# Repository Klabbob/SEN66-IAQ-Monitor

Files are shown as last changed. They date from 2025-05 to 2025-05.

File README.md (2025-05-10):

# IAQ Monitor

An Indoor Air Quality Monitor using the [Sensirion SEN66](https://sensirion.com/de/produkte/katalog/SEN66) sensor and a [LilyGo T-Display-S3](https://lilygo.cc/products/t-display-s3?variant=42284559827125)

<p align="center">
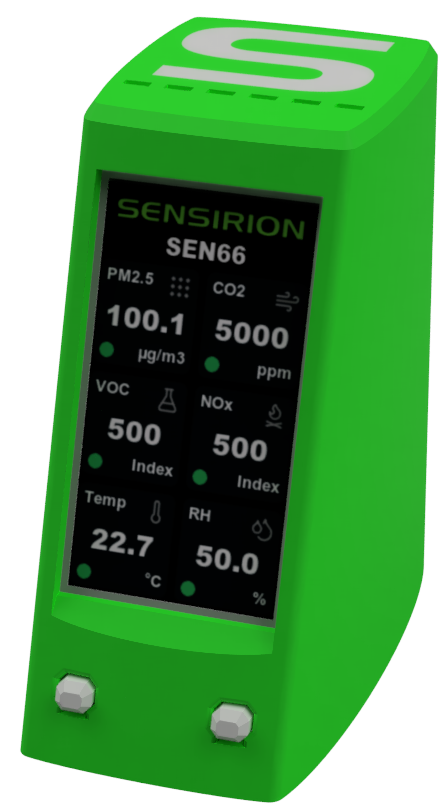
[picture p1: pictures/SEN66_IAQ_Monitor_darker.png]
SEN66 IAQ Monitor
  
</p>

## Features

- Real-time monitoring of:
  - Particle mass concentrations (PM1.0, PM2.5, PM4.0, PM10.0)
  - Temperature
  - Humidity
  - VOC
  - NOx
  - CO2
- Chart screens with 2min30, 60min and 24h resolution
- Settings menu:
  - Perform forced recalibration of CO2
  - Set alititude for CO2 compensation (apply this before the forced recalibration)
  - Switch resolution on chart screen
  - Change screen Brightness
- Serial output with both processed and raw values

## Hardware Requirements

- [Sensirion SEN66](https://sensirion.com/de/produkte/katalog/SEN66), which can be had at many distributors
- [LilyGo T-Display-S3](https://lilygo.cc/products/t-display-s3?variant=42284559827125) (make sure to get the non-touch version without soldered pin headers)
- [SEN5x Jumper Wire](https://sensirion.com/de/produkte/katalog/SEN5x-jumper-wire) - alternatively you can use [Sparkfun JST-GHR-06V Cable](https://www.sparkfun.com/breadboard-to-jst-ghr-06v-cable-6-pin-x-1-25mm-pitch.html), just be ware that the colors are different! Both cables can be had at many distributors.
- [USB C Breackout Board](https://www.sparkfun.com/sparkfun-usb-c-breakout.html) (Knock-offs can also be found on Aliexpress and the likes)
- 3D Printer to print the housing
- M3x10 Bolt
- (optional) [M3 threaded insert](https://www.3djake.com/3djake/threaded-inserts-50-piece-set)

## Software Requirements

- VSCode with PlatformIO (or forks of VSCode like [Cursor](https://www.cursor.com/))

## Hardware Assembly

### 3D Printing

In the [3D Models](3D%20Models) folder, you can find the Fusion 360 source file and STEP-File exports of all the parts that you need. You need the following parts:
- Top Shell - Different versions for:
  - With Logo for dual color printing or without 
  - With heat insert or without if you want to screw directly into the plastic
- Bottom Shell- Two versions for:
  - Original Sparkfun USB C boards with 1.6mm PCB thickness
  - Version for some Aliexpress knockoffs that can be only 1.2mm thick
- Buttons

Print the parts in the following orientation. The only part that needs some paint-on support is the area of the bottom shell where you can find the USB port of the LilyGo T-Display S3

<p align="center">
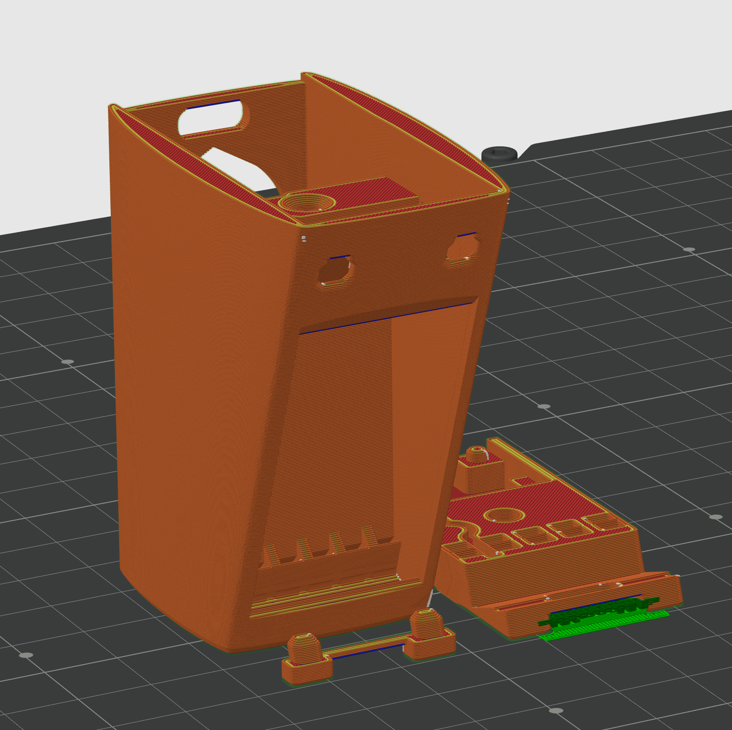
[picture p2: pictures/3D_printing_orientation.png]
3D Print Preview
  
</p>

After printing make sure that the inside part of the top shell where the buttons should sit is flat.

### Wiring

<p align="center">
  Wiring Diagram
</p>

The instruction is for the [SEN5x Jumper Wire](https://sensirion.com/de/produkte/katalog/SEN5x-jumper-wire), if you use the [Sparkfun JST-GHR-06V Cable](https://www.sparkfun.com/breadboard-to-jst-ghr-06v-cable-6-pin-x-1-25mm-pitch.html), just be ware that the colors are different!

- Remove the purple and blue cable from the connector
- cut the remaining 4 cables to a length of 110mm
- from the leftovers cut 75mm of the black and red wire
- Connect the USB C Board
  - 75mm:
    - Red to VBUS
    - Black to GND
- Connect T-Display S3
  - 75mm:
    - Red to 5V
    - Black to GND
  - 110mm with connector:
    - Red to 3V3
    - Black to GND
    - Green to GPIO18
    - Yellow to GPIO17

### Assembly

0. If you chose the version with insert, use the soldering iron to insert the M3 threaded insert in to the top shell
1. Insert the LilyGo T-Display-S3 into the top shell
2. Insert the buttons
3. Connect the SEN66 and push it in
4. Clip in the wires from the SEN66 and push the remaining wires in to the cavity behind the T-Display-S3
5. Insert the USB C breakout board into the bottom shell and push the wires in the canal
6. Close everything up with the screw, make sure not to pinch any wires. Test the buttons for smooth operation. If the they are not clicky, you either have to smooth the surface on the inside where the button sit, or you can try to have the screw a bit looser.

## Installation

1. Clone the repository:
   ```bash
   git clone https://github.com/Klabbob/IAQ-Monitor.git
   ```

2. Open the project in PlatformIO

3. Install dependencies:
   ```bash
   pio lib install
   ```

4. Build and upload to your device

## Sensor Data

<details>
<summary>Sensor Data</summary>

### Processed Values

- Particle Mass Concentrations (μg/m³):
  - PM1.0
  - PM2.5
  - PM4.0
  - PM10.0

- Environmental Parameters:
  - Temperature (°C)
  - Humidity (%RH)

- Air Quality Indices (0-500):
  - VOC Index
  - NOx Index

- Gas Concentration:
  - CO2 (ppm)

### Raw Values

- Environmental Parameters:
  - Raw Humidity: Scaled with factor 100 (RH [%] = value / 100)
  - Raw Temperature: Scaled with factor 200 (T [°C] = value / 200)

- Gas Sensors:
  - Raw VOC: Raw ticks without scale factor
  - Raw NOx: Raw ticks without scale factor
  - Raw CO2: Not interpolated CO₂ concentration [ppm]

### Raw Value Notes

- If humidity or temperature values are unknown, 0x7FFF is returned
- If VOC, NOx, or CO2 values are unknown, 0xFFFF is returned
- During the first 10-11 seconds after power-on or device reset, NOx will be 0xFFFF
- During the first 5-6 seconds after power-on or device reset, CO2 will be 0xFFFF
</details>

## Serial Output

The device outputs data in the following tab-separated format:

```
PM1.0	PM2.5	PM4.0	PM10.0	RH	T	VOC	NOx	CO2	Raw RH	Raw T	Raw VOC	Raw NOx	Raw CO2
12.3	34.5	56.7	78.9	45.6	23.4	120	80	400	45.60	23.40	100	80	400
```

- The first line is a header describing each column.
- The second and subsequent lines are sensor readings, tab-separated, in the order shown above.

## Development

### UI
The UI is built with [SquareLine Studio](https://squareline.io/downloads). Due to the limitiations of the free license tier, the setting screens are designed in a separate project. The projects can be found in the [src/ui_Settings](src/ui_Settings) folder. 

You can make changes to the UI by opening the project file (.spj) in SquareLine Studio. Go to File->Project Settings and set the UI Files Export Path to the `src/ui` or `src/ui_Settings` respecitively as SquareLine Studio only takes absolut paths. Then make your adjustments and go to Export->Export UI Files.

It is necessary to manually assembly the two ui exports. The main screens will be directly exported to the [src/ui](src/ui) folder, the setting screens to the [src/ui_Settings](src/ui_Settings) folder. 

1. Copy over all screen files (ui_XYZScreen.c) to [src/ui](src/ui) from [src/ui_Settings](src/ui_Settings)
2. Copy over all image files (ui_img_XYZ.c) that are not already in [src/ui](src/ui)
3. Copy all unique parts of ui.c and ui.h in [src/ui_Settings](src/ui_Settings) into the respective files in [src/ui](src/ui)
4. Repeat the same for the filelist.txt and CMakeLists.text files.

Contgratulations, you merged both projects. If you add new screens, make sure to update display_task.h and display_task.cpp. If you add a lot of new stuff, you might need to increase LV_MEM_SIZE in lv_conf.h

### Known Bugs

- Screen sometimes not fully refreshing when switching screen showing remenants of previous screens
- ledcWrite function in setDisplayBrightness not always setting 100% duty cycle correctly

### TODO

- [ ] Implement offset compensation based on screen brightness

## License

This project is licensed under the MIT License - see the LICENSE file for details.

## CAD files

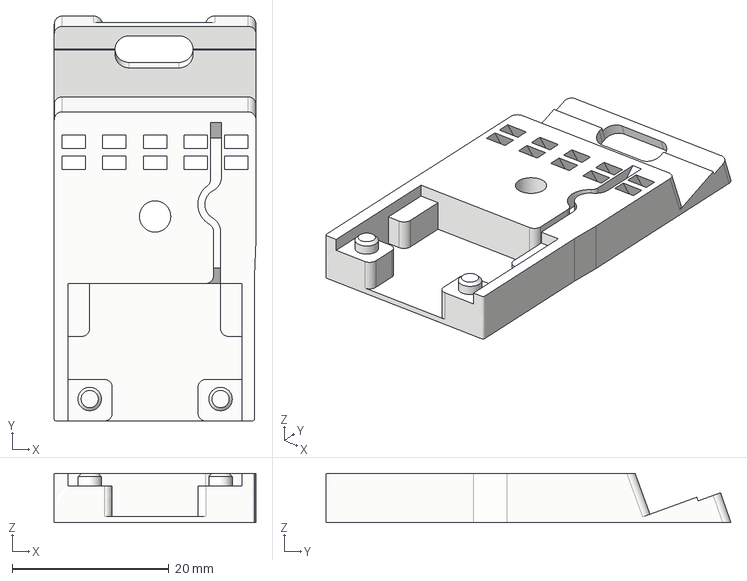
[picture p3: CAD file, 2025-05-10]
3D Models/SEN6x IAQ Bottom Shell 1_6mm.step
25.8 x 51.7 x 6.26 mm

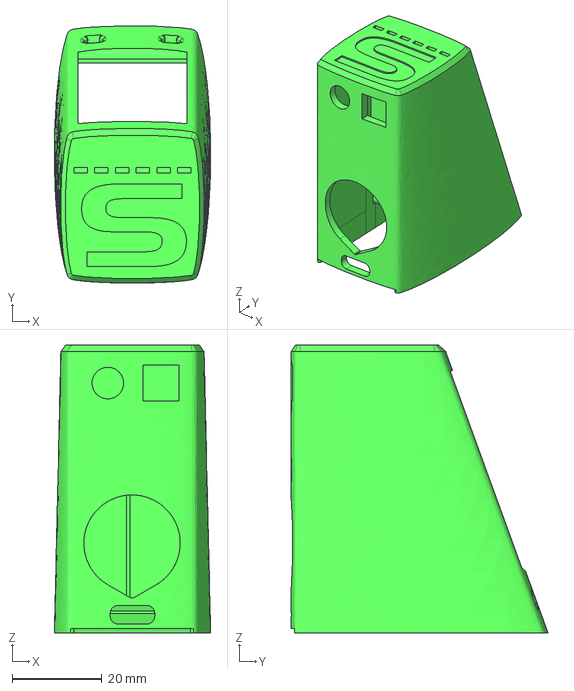
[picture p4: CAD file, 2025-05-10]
3D Models/SEN6x IAQ Top Shell without insert with Logo.step
34.9 x 57.4 x 64.3 mm
Top Shell
Top Shell no insert

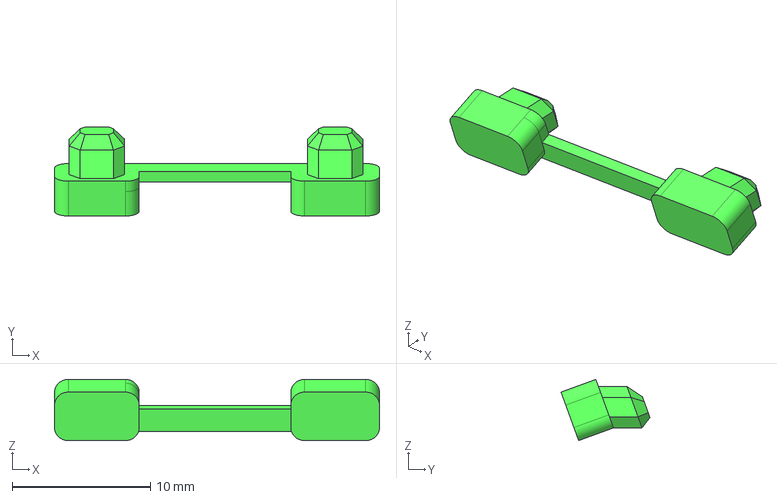
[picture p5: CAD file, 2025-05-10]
3D Models/SEN6x IAQ Buttons.step
23.5 x 6.43 x 4.42 mm

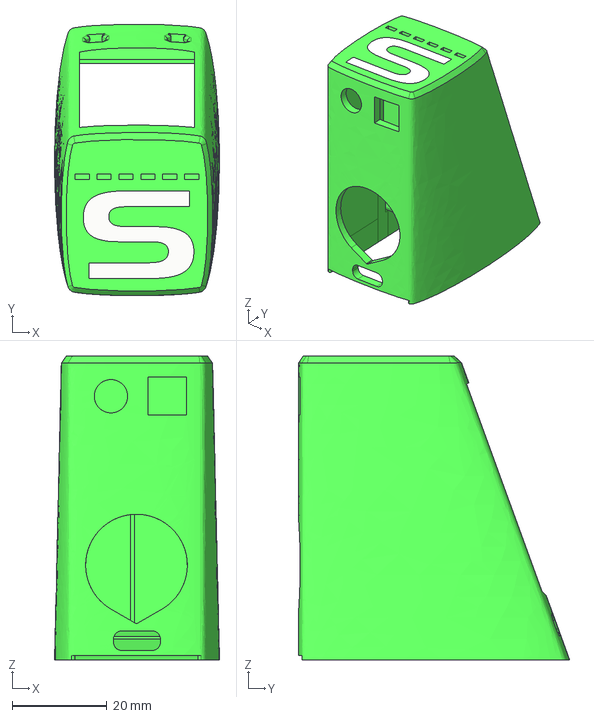
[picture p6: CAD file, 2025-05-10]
3D Models/SEN6x IAQ Top Shell without Logo.step
34.9 x 57.4 x 64.3 mm

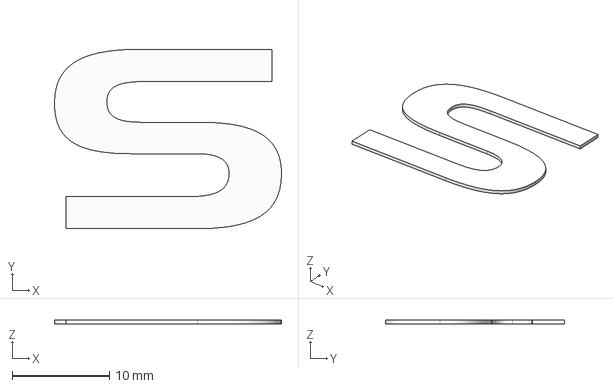
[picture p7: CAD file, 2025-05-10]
3D Models/SEN6x IAQ Logo.step
23.4 x 18.5 x 0.4 mm

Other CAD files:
3D Models/SEN6x IAQ Bottom Shell 1_2mm.step
3D Models/SEN6x IAQ Top Shell with Logo.step
3D Models/SEN6x IAQ Top Shell without insert without Logo.step

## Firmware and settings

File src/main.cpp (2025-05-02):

#include "Arduino.h"
#include <WiFi.h>
#include "esp_bt.h"
#include "esp_bt_main.h"
#include "task_hierarchy.h"
#include "tasks/task_utils.h"
#include "tasks/serial_logging_task.h"
#include "tasks/i2c_scan_task.h"
#include "tasks/live_data_manager.h"
#include "tasks/display_task.h"
#include "tasks/button_handler.h"
#include "definitions.h"

// Global variables
TaskHandle_t xSerialLogTaskHandle = nullptr;
TaskHandle_t xI2CScanTaskHandle = nullptr;

void disableWireless() {
    // Disable WiFi
    WiFi.disconnect(true);  // Disconnect and delete credentials
    WiFi.mode(WIFI_OFF);    // Set WiFi to off mode
    
    // Disable Bluetooth
    btStop();              // Stop Bluetooth
    esp_bt_controller_disable();  // Disable BT controller
    esp_bt_controller_mem_release(ESP_BT_MODE_BTDM);  // Release BT memory
}

void setup() {
    Serial.begin(115200);
    
    #ifdef DEBUG_MODE
    // Wait for serial to be ready
    while (!Serial) delay(100);
    Serial.println("SEN66 Sensor Test Starting...");
    #endif

      // Set CPU frequency to 80MHz
    setCpuFrequencyMhz(80);
    
    // Disable wireless features
    disableWireless();

    // Enable power from 5v Pin or Battery 
    pinMode(PIN_POWER_ON, OUTPUT);
    digitalWrite(PIN_POWER_ON, 1);
    
    // Launch LiveDataManager task first
    if (launchTaskWithVerification(
        LiveDataManager::liveDataManagerTask,
        LIVE_DATA_TASK_NAME,
        LIVE_DATA_STACK_SIZE,
        nullptr,
        TIER_I_PRIORITY,
        &LiveDataManager::xLiveDataManagerTaskHandle
    ) != pdPASS) {
        Serial.println("Failed to create LiveDataManager task");
        while (1) delay(100);
    }
    
    // Launch I2C scan task
    if (launchTaskWithVerification(
        I2CScanTask::i2cScanTask,
        I2C_SCAN_TASK_NAME,
        I2C_STACK_SIZE,
        nullptr,
        TIER_II_PRIORITY,
        &xI2CScanTaskHandle
    ) != pdPASS) {
        Serial.println("Failed to create I2C scan task");
        while (1) delay(100);
    }
    
    #ifdef SERIAL_LOGGING
    // Launch serial logging task
    if (launchTaskWithVerification(
        serialLoggingTask,
        SERIAL_LOG_TASK_NAME,
        DEFAULT_STACK_SIZE,
        nullptr,
        TIER_III_PRIORITY,
        &xSerialLogTaskHandle
    ) != pdPASS) {
        Serial.println("Failed to create serial logging task");
        while (1) delay(100);
    }
    #endif
    // Launch display task
    if (launchTaskWithVerification(
        DisplayTask::displayTask,
        DISPLAY_TASK_NAME,
        DISPLAY_STACK_SIZE,
        nullptr,
        TIER_I_PRIORITY,
        &DisplayTask::xDisplayTaskHandle
    ) != pdPASS) {
        Serial.println("Failed to create display task");
        while (1) delay(100);
    }

    // Launch button task
    if (launchTaskWithVerification(
        ButtonHandler::buttonTask,
        "ButtonTask",
        DEFAULT_STACK_SIZE,
        nullptr,
        TIER_II_PRIORITY,
        &ButtonHandler::xButtonTaskHandle
    ) != pdPASS) {
        Serial.println("Failed to create button task");
        while (1) delay(100);
    }
    
    Serial.println("Tasks initialized successfully!");
    Serial.println("Starting measurements...");
    Serial.println("----------------------------------------");
}

void loop() {
    // Do nothing, all operations being taken care of by tasks
    vTaskSuspend(NULL);  // Suspend the main loop task
} 

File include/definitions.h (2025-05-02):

#pragma once

#include <cstdint>

// uncomment to enable debug mode
// #define DEBUG_MODE

// uncomment to enable serial logging
#define SERIAL_LOGGING

// I2C Configuration
#define SENSOR_I2C_ADDRESS 0x6B
#define SENSOR_READY_CHECK_INTERVAL 1000    // ms
#define SENSOR_READY_RECHECK_TIME 100       // ms


//STAR Engine Parameters:
//  Acceleration
#define K                            20
#define P                            20
#define T1                           100
#define T2                           300

// Slot 0
#define SLOT_0_OFFSET                -620   //-3.1°C scaled by 200
#define SLOT_0_SLOPE                 0      //no slope
#define SLOT_0_TIME_CONSTANT         700    //Tau63 of 700 seconds
#define SLOT_0_SLOT_TIME             0      //Slot 0

// Preferences namespace and key
#define PREF_NAMESPACE              "sensor_config"
#define PREF_ALTITUDE_KEY           "altitude"

/*ESP32S3*/
#define PIN_LCD_BL                   38

#define PIN_LCD_D0                   39
#define PIN_LCD_D1                   40
#define PIN_LCD_D2                   41
#define PIN_LCD_D3                   42
#define PIN_LCD_D4                   45
#define PIN_LCD_D5                   46
#define PIN_LCD_D6                   47
#define PIN_LCD_D7                   48

#define PIN_POWER_ON                 15

#define PIN_LCD_RES                  5
#define PIN_LCD_CS                   6
#define PIN_LCD_DC                   7
#define PIN_LCD_WR                   8
#define PIN_LCD_RD                   9

#define PIN_BUTTON_LEFT              0
#define PIN_BUTTON_RIGHT             14
#define PIN_BAT_VOLT                 4

#define PIN_IIC_SCL                  17
#define PIN_IIC_SDA                  18

#define PIN_TOUCH_INT                16
#define PIN_TOUCH_RES                21

// Decimal point definitions for display values
#define PM_DECIMALS          1  // PM values shown with 1 decimal place
#define CO2_DECIMALS         0  // CO2 shown as integer
#define VOC_DECIMALS         0  // VOC Index shown as integer
#define NOX_DECIMALS         0  // NOx Index shown as integer
#define TEMP_DECIMALS        2  // Temperature shown with 1 decimal place
#define RH_DECIMALS          2  // Relative Humidity shown with 1 decimal place

/**
 * @struct SensorData
 * @brief Structure containing all sensor measurements
 */
struct SensorData {
    // Particle mass concentrations
    float pm1p0;         ///< PM1.0 concentration in µg/m³
    float pm2p5;         ///< PM2.5 concentration in µg/m³
    float pm4p0;         ///< PM4.0 concentration in µg/m³
    float pm10p0;        ///< PM10.0 concentration in µg/m³
    
    // Environmental parameters
    float humidity;      ///< Relative humidity in %
    float temperature;   ///< Temperature in Celsius
    
    // Air quality indices
    float vocIndex;      ///< VOC index
    float noxIndex;      ///< NOx index
    
    // Gas concentration
    float co2;           ///< CO2 concentration in ppm
    
    // Raw values
    int16_t rawHumidity;     ///< Scaled with factor 100: RH [%] = value / 100
    int16_t rawTemperature;  ///< Scaled with factor 200: T [°C] = value / 200
    uint16_t rawVOC;         ///< Raw VOC ticks without scale factor
    uint16_t rawNOx;         ///< Raw NOx ticks without scale factor
    uint16_t rawCO2;         ///< Not interpolated CO₂ concentration [ppm]
    uint32_t runtime_ticks;  // Runtime in ticks since start
};
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

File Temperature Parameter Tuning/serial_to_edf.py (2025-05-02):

import serial
import time
from datetime import datetime
import uuid
import platform
import json
import os

class EDFWriter:
    def __init__(self, port, baudrate=115200, output_dir="Temperature Parameter Tuning"):
        self.serial = serial.Serial(port, baudrate)
        self.output_dir = output_dir
        self.session_id = str(uuid.uuid4())
        self.group_id = str(uuid.uuid4())
        self.sensor_id = "1241021161703511"  # Default sensor ID, can be updated
        
        # Create output directory if it doesn't exist
        if not os.path.exists(output_dir):
            os.makedirs(output_dir)
            
        # VOC and NOx algorithm parameters
        self.voc_params = {
            "algorithm_version": "3.1.0",
            "index_offset": 100,
            "learning_time_offset_hours": 12,
            "learning_time_gain_hours": 12,
            "gating_max_duration_minutes": 180,
            "std_initial": 50,
            "gain_factor": 230,
            "format": 2
        }
        
        self.nox_params = {
            "algorithm_version": "3.1.0",
            "index_offset": 1,
            "learning_time_offset_hours": 12,
            "learning_time_gain_hours": 12,
            "gating_max_duration_minutes": 720,
            "std_initial": 50,
            "gain_factor": 230,
            "format": 2
        }

    def generate_header(self):
        current_time = datetime.now().isoformat()
        hostname = platform.node()
        os_info = f"{platform.system()}-{platform.release()}-{platform.version()}"
        
        header = f"""# EdfVersion=4.0
# Date={current_time}
# MeasurementSession={self.session_id}
# MeasurementGroup={self.group_id}
# HostName={hostname}
# ApplicationName=ControlCenter
# ApplicationVersion=1.45.0
# OperatingSystem={os_info}
# SensorId={self.sensor_id}
# voc_algorithm_parameters={json.dumps(self.voc_params)}
# nox_algorithm_parameters={json.dumps(self.nox_params)}
# Type=float64,Format=.3f,Unit=s\tType=string,Format=\tType=float,Format=.6f,Device=SensorBridge_(7d4776),Device_Serial_Number=SensorBridge-260058000151313137343431,Device_Serial_Number=SensorBridge-260058000151313137343431,Port=2,SensorName=SEN66_green,Sensor_Serial_Number={self.sensor_id},Signal=Mass_Concentration_1p0,Unit=ug/m³,Product=SEN66,Measurement_Frequency=1.0Hz\tType=float,Format=.6f,Device=SensorBridge_(7d4776),Device_Serial_Number=SensorBridge-260058000151313137343431,Port=2,SensorName=SEN66_green,Sensor_Serial_Number={self.sensor_id},Signal=Mass_Concentration_2p5,Unit=ug/m³,Product=SEN66,Measurement_Frequency=1.0Hz\tType=float,Format=.6f,Device=SensorBridge_(7d4776),Device_Serial_Number=SensorBridge-260058000151313137343431,Port=2,SensorName=SEN66_green,Sensor_Serial_Number={self.sensor_id},Signal=Mass_Concentration_4p0,Unit=ug/m³,Product=SEN66,Measurement_Frequency=1.0Hz\tType=float,Format=.6f,Device=SensorBridge_(7d4776),Device_Serial_Number=SensorBridge-260058000151313137343431,Port=2,SensorName=SEN66_green,Sensor_Serial_Number={self.sensor_id},Signal=Mass_Concentration_10p,Unit=ug/m³,Product=SEN66,Measurement_Frequency=1.0Hz\tType=float,Format=.6f,Device=SensorBridge_(7d4776),Device_Serial_Number=SensorBridge-260058000151313137343431,Port=2,SensorName=SEN66_green,Sensor_Serial_Number={self.sensor_id},Signal=Relative_Humidity,Unit=%RH,Product=SEN66,Measurement_Frequency=1.0Hz\tType=float,Format=.6f,Device=SensorBridge_(7d4776),Device_Serial_Number=SensorBridge-260058000151313137343431,Port=2,SensorName=SEN66_green,Sensor_Serial_Number={self.sensor_id},Signal=Temperature,Unit=°C,Product=SEN66,Measurement_Frequency=1.0Hz\tType=float,Format=.6f,Device=SensorBridge_(7d4776),Device_Serial_Number=SensorBridge-260058000151313137343431,Port=2,SensorName=SEN66_green,Sensor_Serial_Number={self.sensor_id},Signal=VOC_Index,Unit=VOC Index,Product=SEN66,Measurement_Frequency=1.0Hz\tType=float,Format=.6f,Device=SensorBridge_(7d4776),Device_Serial_Number=SensorBridge-260058000151313137343431,Port=2,SensorName=SEN66_green,Sensor_Serial_Number={self.sensor_id},Signal=NOx_Index,Unit=NOx Index,Product=SEN66,Measurement_Frequency=1.0Hz\tType=float,Format=.6f,Device=SensorBridge_(7d4776),Device_Serial_Number=SensorBridge-260058000151313137343431,Port=2,SensorName=SEN66_green,Sensor_Serial_Number={self.sensor_id},Signal=Carbon_Dioxide,Unit=ppm,Product=SEN66,Measurement_Frequency=1.0Hz\tType=float,Format=.6f,Device=SensorBridge_(7d4776),Device_Serial_Number=SensorBridge-260058000151313137343431,Port=2,SensorName=SEN66_green,Sensor_Serial_Number={self.sensor_id},Signal=Number_Concentration_0p5,Unit=N/cm³,Product=SEN66,Measurement_Frequency=1.0Hz\tType=float,Format=.6f,Device=SensorBridge_(7d4776),Device_Serial_Number=SensorBridge-260058000151313137343431,Port=2,SensorName=SEN66_green,Sensor_Serial_Number={self.sensor_id},Signal=Number_Concentration_1p0,Unit=N/cm³,Product=SEN66,Measurement_Frequency=1.0Hz\tType=float,Format=.6f,Device=SensorBridge_(7d4776),Device_Serial_Number=SensorBridge-260058000151313137343431,Port=2,SensorName=SEN66_green,Sensor_Serial_Number={self.sensor_id},Signal=Number_Concentration_2p5,Unit=N/cm³,Product=SEN66,Measurement_Frequency=1.0Hz\tType=float,Format=.6f,Device=SensorBridge_(7d4776),Device_Serial_Number=SensorBridge-260058000151313137343431,Port=2,SensorName=SEN66_green,Sensor_Serial_Number={self.sensor_id},Signal=Number_Concentration_4p0,Unit=N/cm³,Product=SEN66,Measurement_Frequency=1.0Hz\tType=float,Format=.6f,Device=SensorBridge_(7d4776),Device_Serial_Number=SensorBridge-260058000151313137343431,Port=2,SensorName=SEN66_green,Sensor_Serial_Number={self.sensor_id},Signal=Number_Concentration_10p,Unit=N/cm³,Product=SEN66,Measurement_Frequency=1.0Hz\tType=float,Format=.6f,Device=SensorBridge_(7d4776),Device_Serial_Number=SensorBridge-260058000151313137343431,Port=2,SensorName=SEN66_green,Sensor_Serial_Number={self.sensor_id},Signal=Relative_Humidity_Raw_Signal,Unit=%RH,Product=SEN66,Measurement_Frequency=1.0Hz\tType=float,Format=.6f,Device=SensorBridge_(7d4776),Device_Serial_Number=SensorBridge-260058000151313137343431,Port=2,SensorName=SEN66_green,Sensor_Serial_Number={self.sensor_id},Signal=Temperature_Raw_Signal,Unit=°C,Product=SEN66,Measurement_Frequency=1.0Hz\tType=float,Format=.6f,Device=SensorBridge_(7d4776),Device_Serial_Number=SensorBridge-260058000151313137343431,Port=2,SensorName=SEN66_green,Sensor_Serial_Number={self.sensor_id},Signal=VOC_Raw_Signal,Unit=ticks,Product=SEN66,Measurement_Frequency=1.0Hz\tType=float,Format=.6f,Device=SensorBridge_(7d4776),Device_Serial_Number=SensorBridge-260058000151313137343431,Port=2,SensorName=SEN66_green,Sensor_Serial_Number={self.sensor_id},Signal=NOx_Raw_Signal,Unit=ticks,Product=SEN66,Measurement_Frequency=1.0Hz\tType=float,Format=.6f,Device=SensorBridge_(7d4776),Device_Serial_Number=SensorBridge-260058000151313137343431,Port=2,SensorName=SEN66_green,Sensor_Serial_Number={self.sensor_id},Signal=Raw_Carbon_Dioxide,Unit=ppm,Product=SEN66,Measurement_Frequency=1.0Hz
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

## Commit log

2025-03-16 Updated .cursorrules to include detailed guidelines on code style, naming conventions, PlatformIO best practices, LVGL UI development, sensor integration, and LilyGo T-Display S3 hardware considerati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
2025-03-16 Initial commit: Basic SEN66 sensor implementation
2025-03-16 Update README with complete sensor data documentation and raw values
2025-03-20 integrated sensor manager into i2c_scan_task
2025-04-05 feat: implement indicator states for all sensor parameters - Add centralized threshold definitions in definitions.h - Update display task to use threshold-based indicator states - Implement proper in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
    [definitions.h, display_task.cpp]
2025-04-14 Main Screen finished refactor: update task headers to include definitions.h - Add indicator state enumeration to display_task.h - Introduce update functions for tile indicators in display_task.h - Cl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
2025-04-21 Settings can now be entered through long pressing on settings screen. Settings work visualy, currently no acctual function yet.
2025-04-29 Chart time and screen brightness can be set through settings. Bug in screen brightness present that does not always set 100% duty cycle correctly.
    [display_task.cpp, display_task.h]
2025-04-30 improved handling of rapid button pressing
2025-05-02 charts now reset when altitude or FRC is applied as the sensor is restarted and altitude is safed persistently
    [definitions.h, display_task.cpp, display_task.h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]
2025-05-03 FRC now displays messages during operation and shows the status afterwards including the correction value
    [display_task.cpp, display_task.h, i2c_scan_task.cpp]
2025-05-07 Update Wiring in Readme
2025-05-08 fix error in buffer calculation for 60min and 24h chart points
    [display_task.cpp]
2025-05-08 switch image to darker rendering
2025-05-10 Update platformio.ini to exclude unnecessary directories and enhance README, add SquareLine Studio source, add 3D Models
    [SEN6x IAQ Bottom Shell 1_2mm.step, SEN6x IAQ Bottom Shell 1_6mm.step, SEN6x IAQ Buttons.step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]
2025-05-10 Fix wiring mistake on picture
2025-05-10 add alternative cable option to readme
2025-07-04 fix a bug where PM values above 3276.6ug/m^3 led to an overflow of the datatype of the charts, leading to negative values being shown
    [display_task.cpp]
